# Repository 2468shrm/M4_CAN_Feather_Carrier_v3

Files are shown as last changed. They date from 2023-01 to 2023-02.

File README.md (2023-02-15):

# M4_CAN_Feather_Carrier_v3

## Board Layout
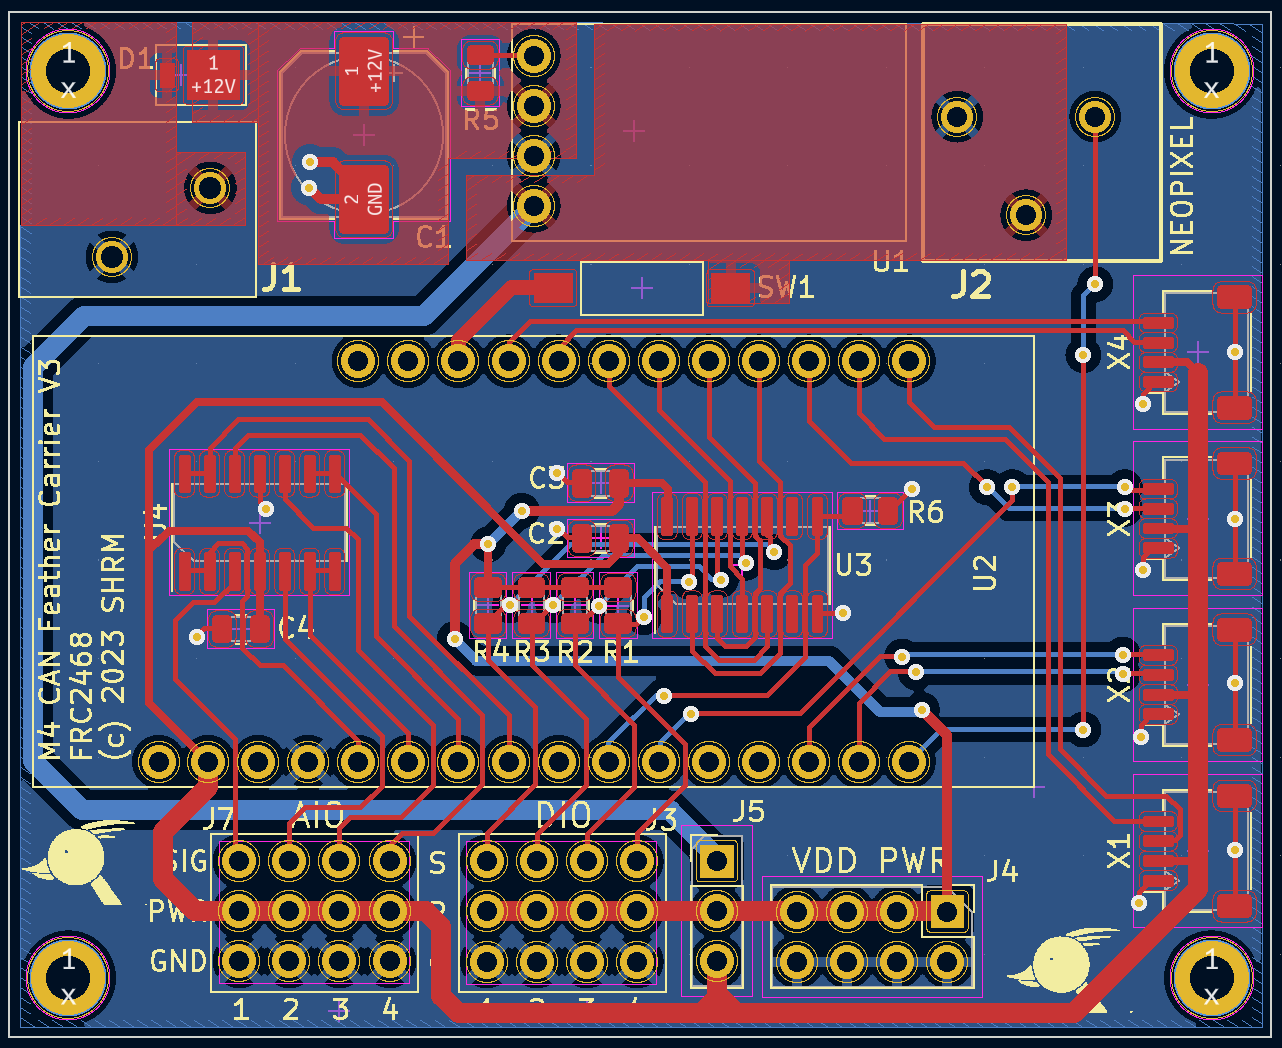
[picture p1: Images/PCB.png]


## Changes from V2

The changes from [V2](https://github.com/2468shrm/M4_CAN_Feather_Carrier_v2) of this
board are largely layout/component positioning. The following
are the changes:
- DIO voltage selector jumper changed pin assignments
- All stake headers are moved to the same edge of the board (bottom edge). It still selects between 5V and 3.3V.
- All STEMMA QT/QWIIC connectors are moved to the same edge of the board (right edge).
- Screw terminals for power and NEOPIXEL are replaced with WAGO 250-series connectors. These are the same connectors used in REV products (CAN, low-current power, etc.).
- The board size changed to 64 x 52 mm.
- The mounting holes are consistently 3 mm from their respective edges.
- The orientation of the ICs (level shifter and analog buffer) are in the same orientation.

Other than that, there are minor changes to make assembly simpler.  Primarily this includes
changing the two ICs so that pin 1 is in the same orientation (V2 had pin 1 pointing in
oppposite directions and sometimes one might forget).

A PDF copy of the schematic [here](https://github.com/2468shrm/M4_CAN_Feather_Carrier_v3/blob/main/Images/Schematic.pdf).

## Checkout Status

This board was fabbed at JLCPCB during the week of 30 Jan, 2023 and articles received
(plus solder stencil). One article has been assembled and the following has been tested:
- Power input filter
- 5V supply
- X1 (I2C/STEMMA QR/QWIIC) interface
- NeoPixel interface

Not yet tested:
- X2-X4
- Level shifter and DIO interface
- Analog buffer and AI interface

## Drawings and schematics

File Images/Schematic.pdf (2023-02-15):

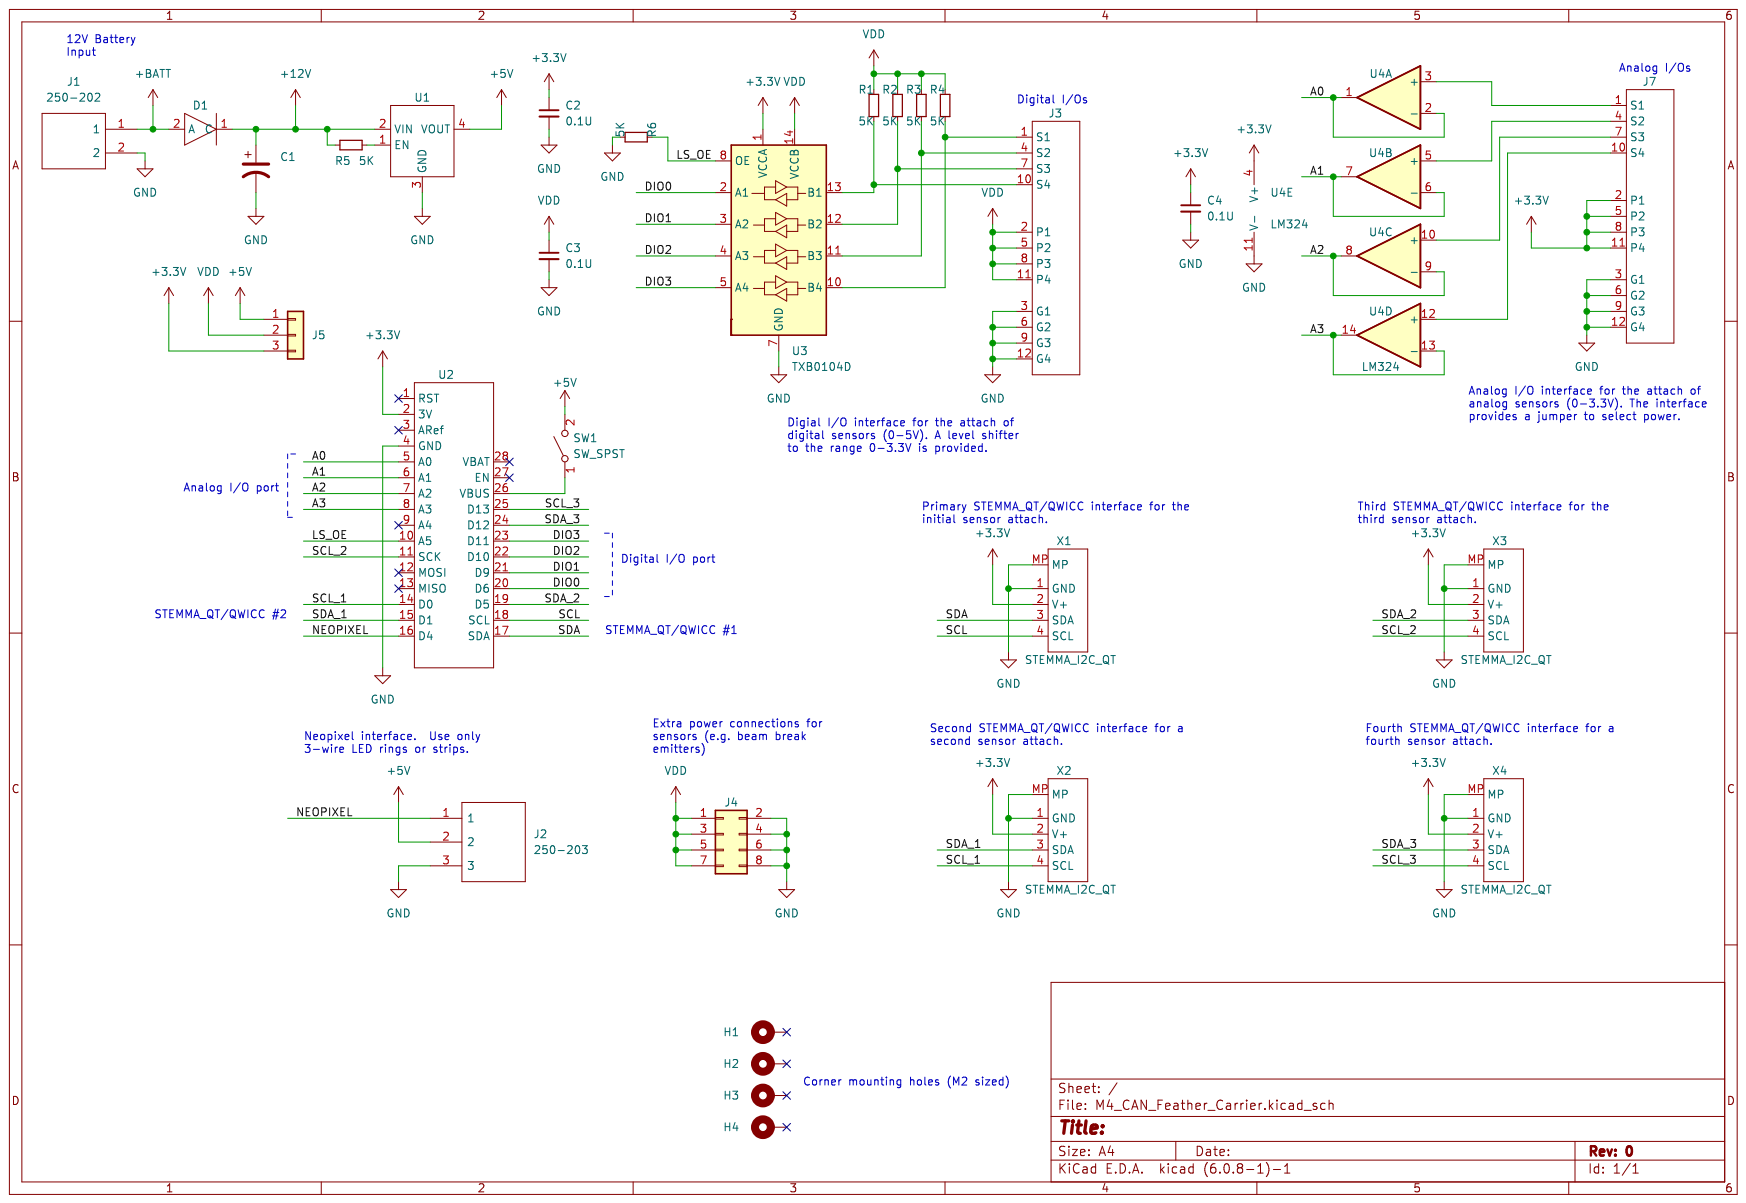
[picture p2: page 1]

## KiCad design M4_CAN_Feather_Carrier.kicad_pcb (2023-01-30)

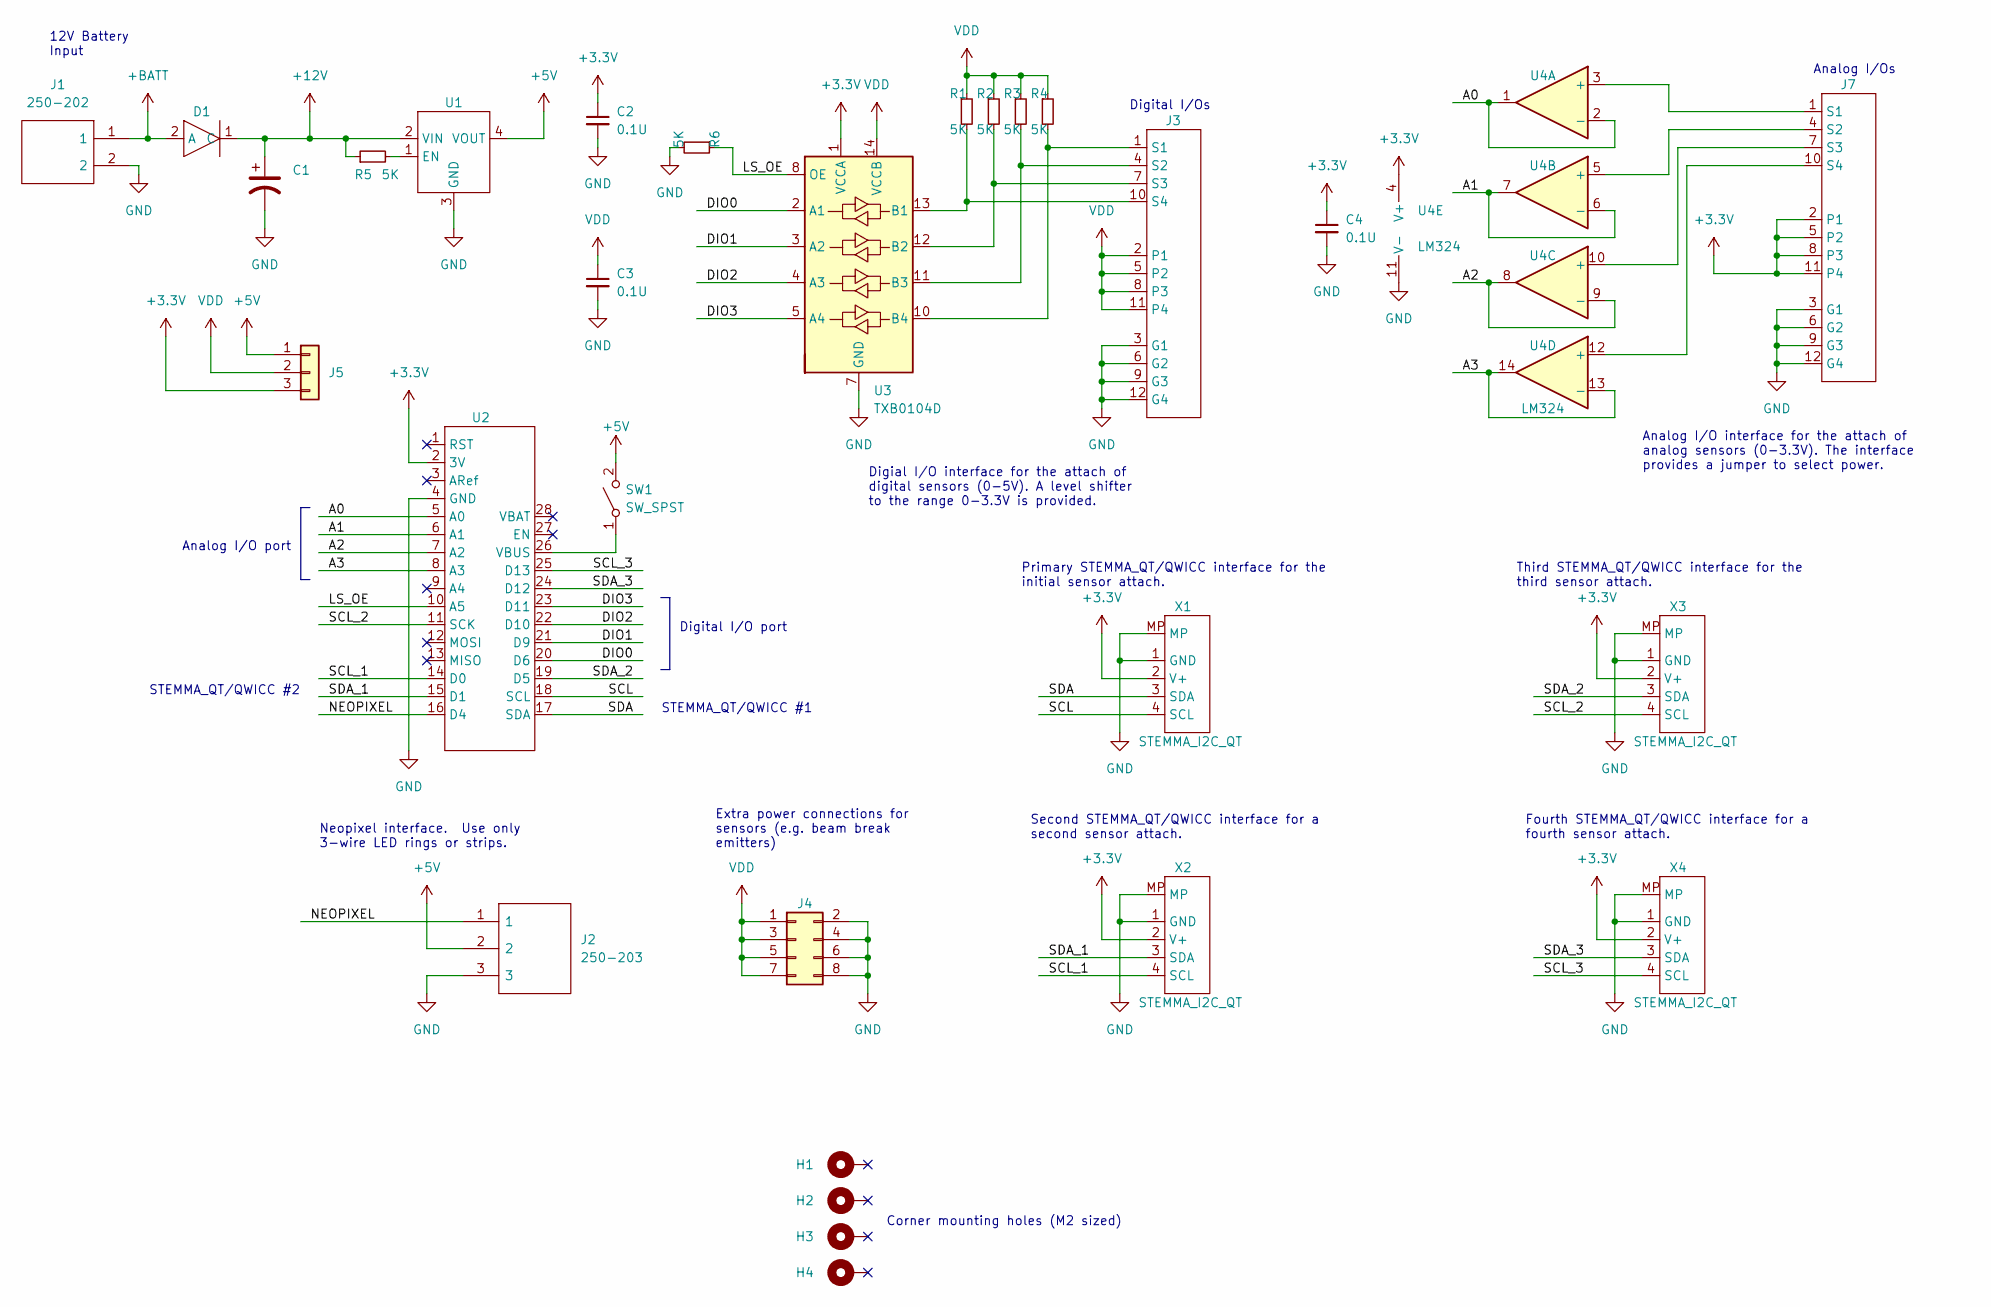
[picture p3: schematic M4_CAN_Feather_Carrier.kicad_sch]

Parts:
C1: 10u; CP_Elec_8x10
C2, C3, C4: 0.1U; C_0805_2012Metric
D1: UPR20e3; DO-216
H1, H2, H3, H4: MountingHole_Pad; MountingHole_2.2mm_M2_DIN965_Pad
J1: 250-202; 250202; Manufacturer_Part_Number 250-202
J2: 250-203; 250-203_1; Manufacturer_Part_Number 250-203
J3, J7: conn_04_03; conn_04x03
J4: Conn_02x04_Odd_Even; PinHeader_2x04_P2.54mm_Vertical
J5: Conn_01x03; PinHeader_1x03_P2.54mm_Vertical
R1, R2, R3, R4, R5, R6: 5K; R_0805_2012Metric
SW1: SW_SPST; SPST-KJ01
U1: Weewooday-820
U2: Feather_M4_CAN_Express
U3: TXB0104D; SOIC-14_3.9x8.7mm_P1.27mm
U4: LM324; SOIC-14_3.9x8.7mm_P1.27mm
X1, X2, X3, X4: STEMMA_I2C_QT; JST_SH_SM04B-SRSS-TB_1x04-1MP_P1.00mm_Horizontal

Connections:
+3.3V: C2.1, C4.1, J5.3, J7.2 (P1), J7.5 (P2), J7.8 (P3), J7.11 (P4), U2.2 (3V), U3.1 (VCCA), U4.4 (V+), X1.2 (V+), X2.2 (V+), X3.2 (V+), X4.2 (V+)
+5V: J2.2, J5.1, SW1.2 (B), U1.4 (VOUT)
+12V: C1.1, D1.1 (C), R5.1, U1.2 (VIN)
+BATT: D1.2 (A), J1.1
/A0: U2.5 (A0), U4.1, U4.2 (-)
/A1: U2.6 (A1), U4.6 (-), U4.7
/A2: U2.7 (A2), U4.8, U4.9 (-)
/A3: U2.8 (A3), U4.13 (-), U4.14
/DIO0: U2.20 (D6), U3.2 (A1)
/DIO1: U2.21 (D9), U3.3 (A2)
/DIO2: U2.22 (D10), U3.4 (A3)
/DIO3: U2.23 (D11), U3.5 (A4)
/LS_OE: R6.1, U2.10 (A5), U3.8 (OE)
/NEOPIXEL: J2.1, U2.16 (D4)
/SCL: U2.18 (SCL), X1.4 (SCL)
/SCL_1: U2.14 (D0), X2.4 (SCL)
/SCL_2: U2.11 (SCK), X3.4 (SCL)
/SCL_3: U2.25 (D13), X4.4 (SCL)
/SDA: U2.17 (SDA), X1.3 (SDA)
/SDA_1: U2.15 (D1), X2.3 (SDA)
/SDA_2: U2.19 (D5), X3.3 (SDA)
/SDA_3: U2.24 (D12), X4.3 (SDA)
GND: C1.2, C2.2, C3.2, C4.2, J1.2, J2.3, J3.3 (G1), J3.6 (G2), J3.9 (G3), J3.12 (G4), J4.2, J4.4, J4.6, J4.8, J7.3 (G1), J7.6 (G2), J7.9 (G3), J7.12 (G4), R6.2, U1.3 (GND), U2.4 (GND), U3.7 (GND), U4.11 (V-), X1.1 (GND), X1.MP, X2.1 (GND), X2.MP, X3.1 (GND), X3.MP, X4.1 (GND), X4.MP
unnamed: J3.1 (S1), R4.2, U3.10 (B4)
unnamed: J3.4 (S2), R3.2, U3.11 (B3)
unnamed: J3.7 (S3), R2.2, U3.12 (B2)
unnamed: J3.10 (S4), R1.2, U3.13 (B1)
unnamed: J7.1 (S1), U4.3 (+)
unnamed: J7.4 (S2), U4.5 (+)
unnamed: J7.7 (S3), U4.10 (+)
unnamed: J7.10 (S4), U4.12 (+)
unnamed: R5.2, U1.1 (EN)
unnamed: SW1.1 (A), U2.26 (VBUS)
VDD: C3.1, J3.2 (P1), J3.5 (P2), J3.8 (P3), J3.11 (P4), J4.1, J4.3, J4.5, J4.7, J5.2, R1.1, R2.1, R3.1, R4.1, U3.14 (VCCB)

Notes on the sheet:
Corner mounting holes (M2 sized)
Digital I/Os
Analog I/Os
Third STEMMA_QT/QWICC interface for the third sensor attach.
Primary STEMMA_QT/QWICC interface for the initial sensor attach.
Extra power connections for sensors (e.g. beam break emitters)
Digial I/O interface for the attach of digital sensors (0-5V). A level shifter to the range 0-3.3V is provided.
Second STEMMA_QT/QWICC interface for a second sensor attach.
Digital I/O port
Analog I/O port
STEMMA_QT/QWICC #1
12V Battery Input
STEMMA_QT/QWICC #2
Analog I/O interface for the attach of analog sensors (0-3.3V). The interface provides a jumper to select power.
Neopixel interface. Use only 3-wire LED rings or strips.
Fourth STEMMA_QT/QWICC interface for a fourth sensor attach.

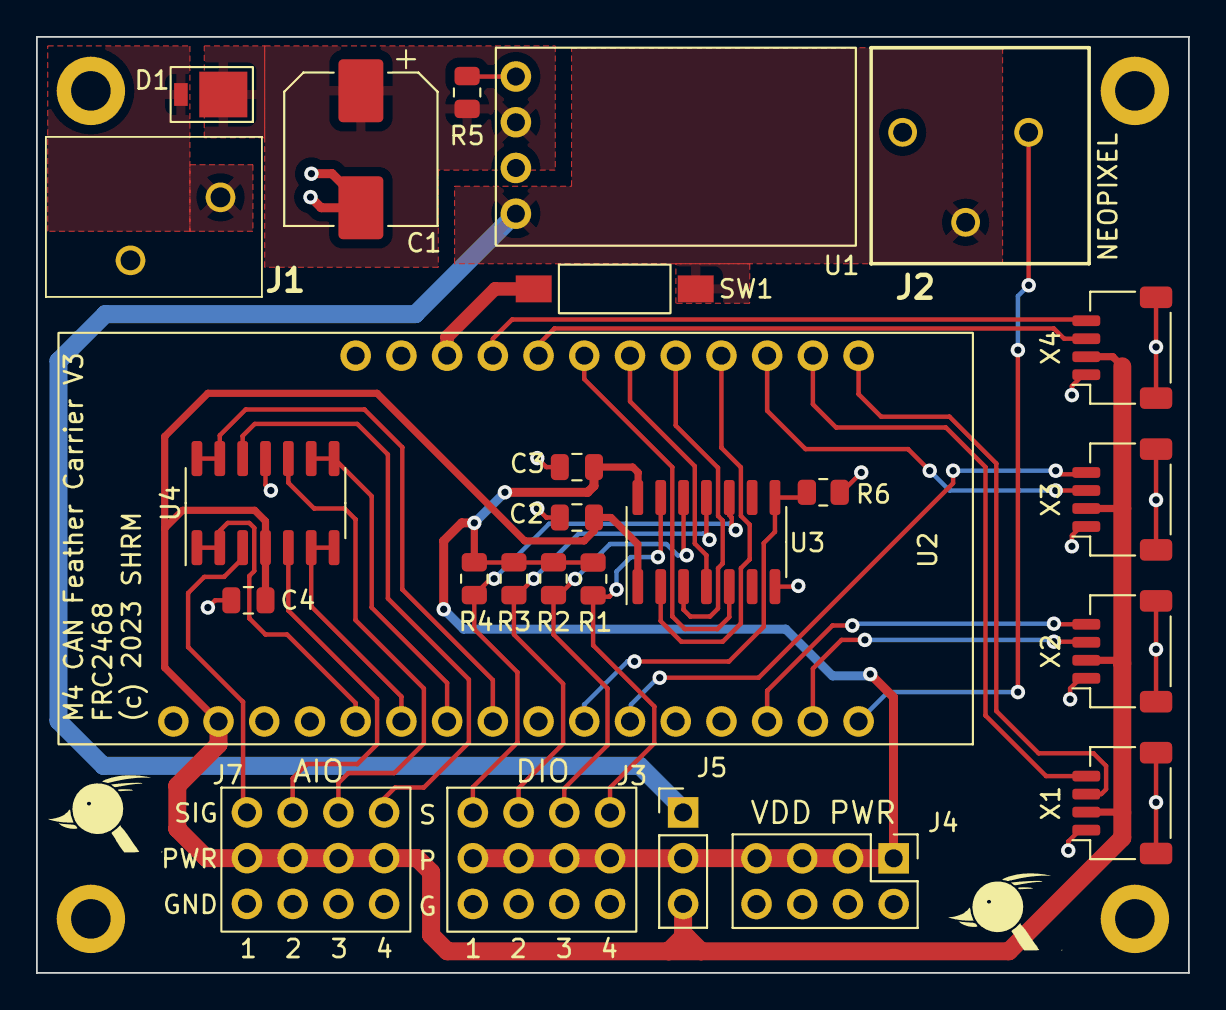
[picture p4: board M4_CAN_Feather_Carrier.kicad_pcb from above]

Board: 2 copper layers, 64.0 x 52.0 mm, 30 parts (0 on the bottom side), 34 nets.

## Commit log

2023-01-30 KiCAD files
    [M4_CAN_Feather_Carrier.kicad_pcb, M4_CAN_Feather_Carrier.kicad_sch]
2023-01-30 Gerber files & zip as uploaded to PCB manufacturer
    [M4_CAN_Feather_Carrier-B_Cu.gbr, M4_CAN_Feather_Carrier-B_Mask.gbr, M4_CAN_Feather_Carrier-B_Paste.gbr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]
2023-01-30 added PCB image
2023-02-15 add schematic to images

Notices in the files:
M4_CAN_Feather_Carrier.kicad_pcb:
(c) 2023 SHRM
